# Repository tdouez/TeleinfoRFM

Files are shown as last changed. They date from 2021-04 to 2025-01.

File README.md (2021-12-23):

//--------------------------------------------------------------------
//   __|              _/           _ )  |
//   _| |  |   ` \    -_)   -_)    _ \  |   -_)  |  |   -_)
//  _| \_,_| _|_|_| \___| \___|   ___/ _| \___| \_,_| \___|
//--------------------------------------------------------------------
# TeleinfoRFM

Interface Téléinfo pour compteur Linky avec MySensors - version compatible modes historique et standard 

Projet utilisant un Arduino Pro mini et un module RFM95w

- Description disponible sur http://fumeebleue.fr

------------------------------------------------------------------------------------
Code mise à disposition selon les termes de la Licence Creative Commons Attribution
Pas d’Utilisation Commerciale.
Partage dans les Mêmes Conditions 4.0 International.
------------------------------------------------------------------------------------

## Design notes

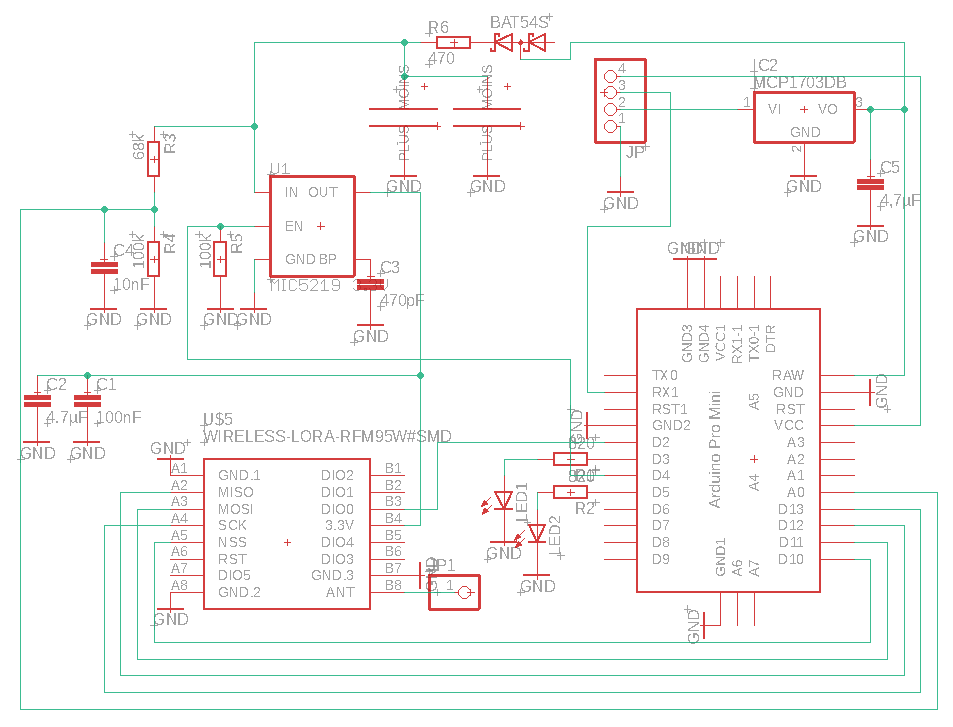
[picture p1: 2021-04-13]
Circuit TeleinfoRFM.png

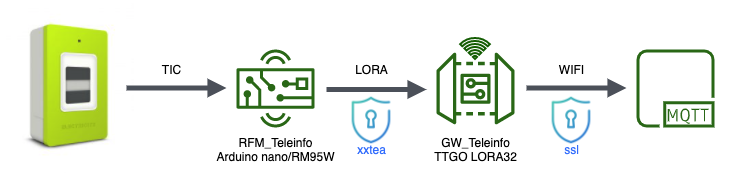
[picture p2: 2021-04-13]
TeleinfoRFM0.png

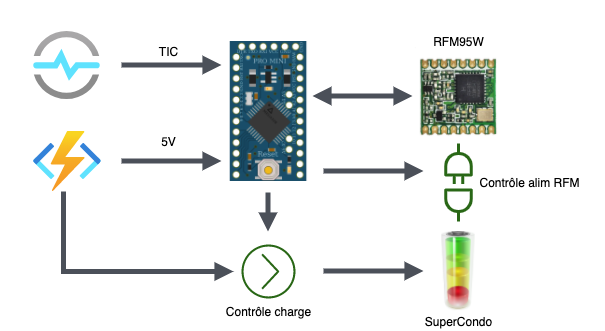
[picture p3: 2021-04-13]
TeleinfoRFM1.png

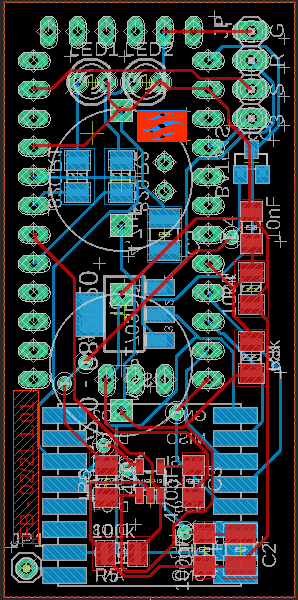
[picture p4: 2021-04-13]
PCB TeleinfoRFM.png

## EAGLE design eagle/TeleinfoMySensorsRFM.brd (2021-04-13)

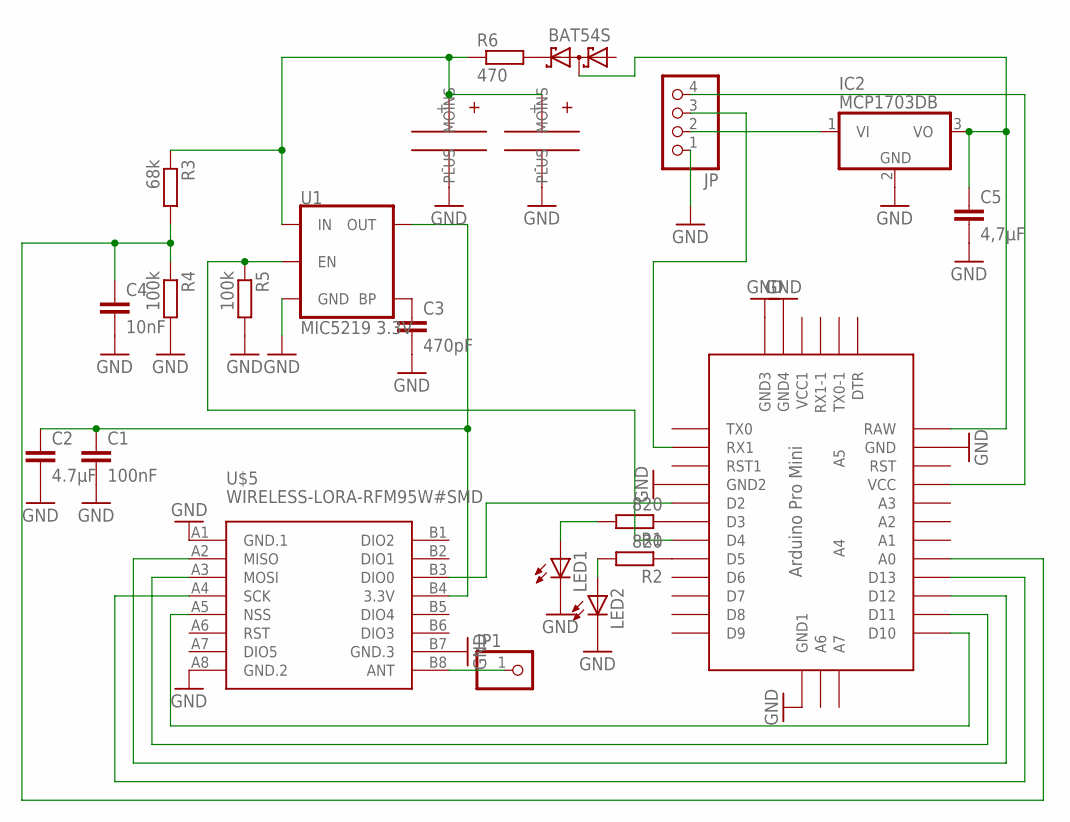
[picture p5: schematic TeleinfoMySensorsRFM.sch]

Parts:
C1: 100nF; C1206
C2: 4.7µF; C1210
C3: 470pF; C1206
C4: 10nF; C1206
C5: 4,7µF; C1210
D3: BAT54S; SOT23
IC2: MCP1703DB; SOT223
JP: PINHD-1X4; 1X04
JP1: PINHD-1X1; 1X01
LED1, LED2: LED3MM
R1, R2: 820; M1206
R3: 68k; M1206
R4, R5: 100k; M1206
R6: 470; M1206
U1: MIC5219 3.3V; SOT23-5
U$1: ABK-PRO-MINI
U$2, U$6: SUPERCAPA10
U$5: WIRELESS-LORA-RFM95W#SMD

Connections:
GND: C1.2, C2.2, C3.2, C4.2, C5.2, IC2.2 (GND), JP.1, LED1.K (C), LED2.K (C), R4.2, R5.2, U1.2 (GND), U$1.GND, U$1.GND1 (GND2), U$1.GND2 (GND3), U$1.GND3 (GND4), U$1.GND4 (GND1), U$2.- (MOINS), U$5.A1 (GND.1), U$5.A8 (GND.2), U$5.B7 (GND.3), U$6.- (MOINS)
unnamed: JP1.1, U$5.B8 (ANT)
unnamed: LED2.A, R2.2
unnamed: U$1.D12, U$5.A2 (MISO)
unnamed: R1.1, U$1.D3
unnamed: IC2.1 (VI), JP.2
unnamed: U$1.D11, U$5.A3 (MOSI)
unnamed: U$1.D13, U$5.A4 (SCK)
unnamed: U$1.D10, U$5.A5 (NSS)
unnamed: R2.1, U$1.D5
unnamed: U$1.D2, U$5.B3 (DIO0)
unnamed: LED1.A, R1.2
unnamed: JP.3, U$1.RX1
unnamed: C3.1, U1.4 (BP)
unnamed: C5.1, D3.3 (C1A2), IC2.3 (VO), U$1.RAW
unnamed: R5.1, U1.3 (EN), U$1.D4
unnamed: C4.1, R3.2, R4.1, U$1.A0
unnamed: C1.1, C2.1, U1.5 (OUT), U$5.B4 (3.3V)
unnamed: JP.4, U$1.VCC
unnamed: D3.2 (C2), R6.2
unnamed: R3.1, R6.1, U1.1 (IN), U$2.+ (PLUS), U$6.+ (PLUS)

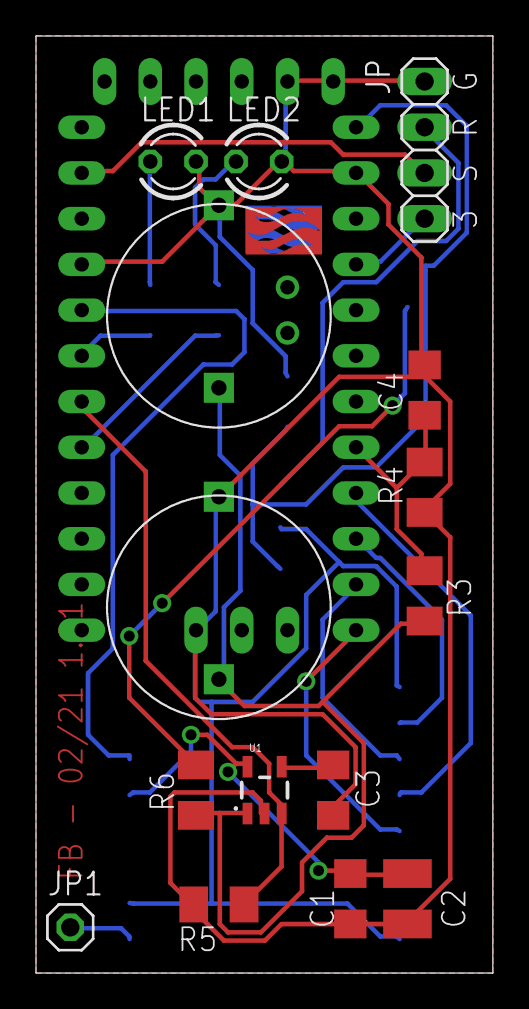
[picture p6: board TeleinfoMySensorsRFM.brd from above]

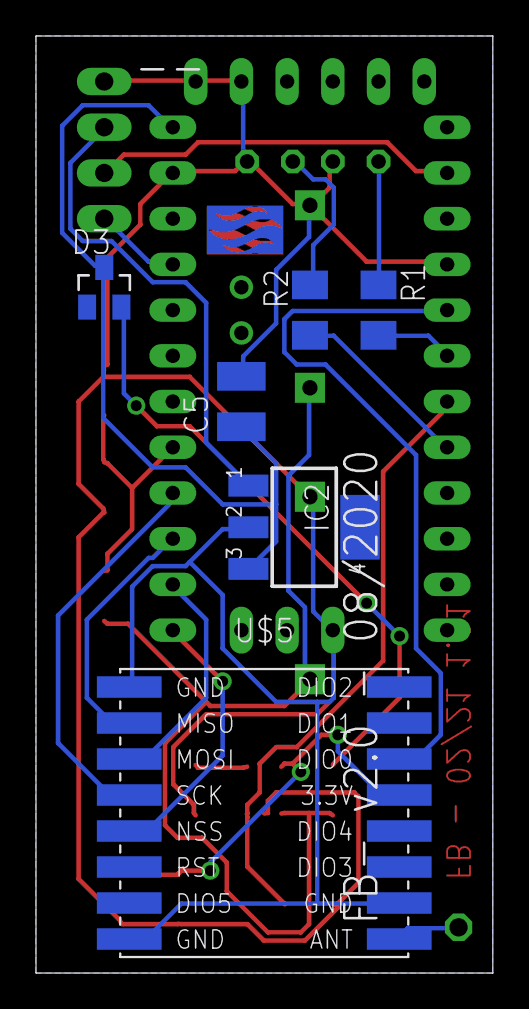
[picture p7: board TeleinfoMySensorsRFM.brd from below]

Board: 2 copper layers, 25.4 x 52.1 mm, 24 parts (7 on the bottom side), 21 nets.

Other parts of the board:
U$3, U$4: FB

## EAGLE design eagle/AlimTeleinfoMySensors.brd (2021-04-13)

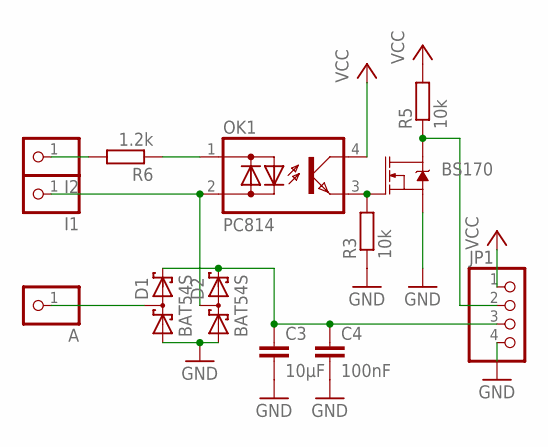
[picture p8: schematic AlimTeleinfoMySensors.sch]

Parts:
A: PINHD-1X1; 1X01
BS170: MOSFET-NCH-BSS138; SOT23-3
C3: 10µF; C1210
C4: 100nF; C1206
D1, D2: BAT54S; SOT23
I1, I2: PINHD-1X1; 1X01
JP1: PINHD-1X4; 1X04
OK1: PC814; DIL04
R3, R5: 10k; M1206
R6: 1.2k; M1206

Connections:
GND: BS170.2 (S), C3.2, C4.2, D1.1 (A1), D2.1 (A1), JP1.4, R3.1
unnamed: I2.1, R6.2
unnamed: D2.3 (C1A2), I1.1, OK1.2 (AC2)
unnamed: BS170.3 (D), JP1.2, R5.1
unnamed: C3.1, C4.1, D1.2 (C2), D2.2 (C2), JP1.3
unnamed: OK1.1 (AC1), R6.1
unnamed: BS170.1 (G), OK1.3 (E), R3.2
unnamed: A.1, D1.3 (C1A2)
VCC: JP1.1, OK1.4 (C), R5.2

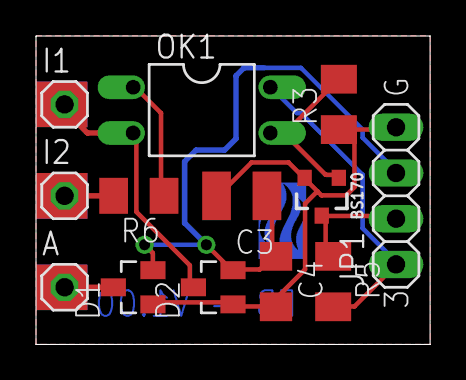
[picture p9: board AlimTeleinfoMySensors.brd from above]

Board: 2 copper layers, 21.9 x 17.1 mm, 14 parts (0 on the bottom side), 9 nets.

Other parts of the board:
U$1: FB

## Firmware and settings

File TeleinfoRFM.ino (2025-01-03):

//--------------------------------------------------------------------
//                 +/
//                 `hh-
//        ::        /mm:
//         hy`      -mmd
//         omo      +mmm.  -+`
//         hmy     .dmmm`   od-
//        smmo    .hmmmy    /mh
//      `smmd`   .dmmmd.    ymm
//     `ymmd-   -dmmmm/    omms
//     ymmd.   :mmmmm/    ommd.
//    +mmd.   -mmmmm/    ymmd-
//    hmm:   `dmmmm/    smmd-
//    dmh    +mmmm+    :mmd-
//    omh    hmmms     smm+
//     sm.   dmmm.     smm`
//      /+   ymmd      :mm
//           -mmm       +m:
//            +mm:       -o
//             :dy
//              `+:
//--------------------------------------------------------------------
//   __|              _/           _ )  |
//   _| |  |   ` \    -_)   -_)    _ \  |   -_)  |  |   -_)
//  _| \_,_| _|_|_| \___| \___|   ___/ _| \___| \_,_| \___|
//--------------------------------------------------------------------
// Code mise à disposition selon les termes de la Licence Creative Commons Attribution
// Pas d’Utilisation Commerciale.
// Partage dans les Mêmes Conditions 4.0 International.
//--------------------------------------------------------------------
// Trame : $origine;libelle;donnees   (libellé & donnnées)
//--------------------------------------------------------------------
// 2021/01/15 - FB V1.0.0
// 2021/06/11 - FB V1.0.1
// 2021/07/01 - FB V1.0.2 - Add ETIQU_URMS1..3
// 2021/11/21 - FB V1.0.3 - Bug fix  modes triphasé et producteur
// 2021/12/08 - FB V2.0.0 - Utilisation de la librairie libTeleinfo (https://github.com/hallard/LibTeleinfo) et chg protocole vers GW
// 2021/12/27 - FB V2.0.1 - Fix bug aléatoire, blocage envoi data
// 2022/01/07 - FB V2.0.2 - Optimisation utilisation mémoire et emissions datas. Ajout détection vitesse TIC.
// 2022/01/11 - FB V2.0.3 - Suppression warning et modif gestion timeout vitesse TIC
// 2022/01/23 - FB V2.0.4 - Correction sur détection TIC historique
// 2022/06/25 - FB V2.0.5 - Optimisation mémoire
// 2022/09/25 - FB V2.0.6 - Correction sur détection TIC standard
// 2023/03/23 - FB V2.0.7 - Ajout indication réception TIC et optimisation mémoire
// 2023/03/30 - FB V2.0.8 - Correction blocage aléatoire module, frequence maj 15 à 20s, clignotement durant charge condo
// 2023/05/04 - FB V2.0.9 - Amélioration détection mode TIC historique/standard
// 2023/06/03 - FB V2.0.10 - Correction detection TIC historique
// 2025/01/03 - FB V2.0.11 - Ajout compatibilité avec le Arduino Pro Micro
//--------------------------------------------------------------------

#include <Arduino.h>
#include <SPI.h>
#include <LoRa.h>
#include <LibTeleinfo.h>

//#define DEBUG_TIC

#ifdef __arm__
// should use uinstd.h to define sbrk but Due causes a conflict
extern "C" char* sbrk(int incr);
#else  // __ARM__
extern char *__brkval;
#endif  // __arm__

#define VERSION   "v2.0.11"

#define ENTETE  "$"

#define POWER_PIN         4
#define TELEINFO_LED_PIN  3   // Teleinfo LED
#define CHARGE_LED_PIN    5   // Charge LED

//-------------------------------------------------------------------------------------
// Seuil : 4,5v à l'entrée du régulateur 3,3v > 4,5v*100k/(100k+68k)=2,68v sur A0
//                                                 3,3v->1023 => 2,68->830
//-------------------------------------------------------------------------------------
#define SEUIL_CHARGE_FULL   815
#define SEUIL_CHARGE_98     805

#define RFM_TX_POWER   10   // 5..23 dB

boolean full_tic = true;
boolean flag_tic = true;
boolean flag_send_tic = true;
boolean flag_adresse_tic;
boolean flag_boot;

const char char_ADCO[] PROGMEM = "ADCO";
const char char_ADSC[] PROGMEM = "ADSC";
const unsigned long SEND_FREQUENCY_FULL = 180000; // 3mn, Minimum time between send (in milliseconds). 
const unsigned long SEND_FREQUENCY_TIC  =  20000; // 15s,  Minimum time between send (in milliseconds). 
unsigned long lastTime_full = 0;
unsigned long lastTime_tic = 0;
char adresse_compteur[13];
_Mode_e mode_tic;

TInfo tinfo;

/*
// ---------------------------------------------------------------- 
// freeMemory
// ---------------------------------------------------------------- 
int freeMemory() {
  char top;
#ifdef __arm__
  return &top - reinterpret_cast<char*>(sbrk(0));
#elif defined(CORE_TEENSY) || (ARDUINO > 103 && ARDUINO != 151)
  return &top - __brkval;
#else  // __arm__
  return __brkval ? &top - __brkval : &top - __malloc_heap_start;
#endif  // __arm__
}

// ---------------------------------------------------------------- 
// freeMemory
// ---------------------------------------------------------------- 
void affiche_freeMemory() {
	Serial.print(F("SRAM:"));
	Serial.println(freeMemory());
}
*/

// ---------------------------------------------------------------- 
// change_etat_led
// ---------------------------------------------------------------- 
void change_etat_led(uint8_t led)
{
  static uint8_t led_state;

  led_state = !led_state;
  digitalWrite(led, led_state);

}

// ---------------------------------------------------------------- 
// clignote_led
// ---------------------------------------------------------------- 
void clignote_led(uint8_t led, uint8_t nbr, int16_t delais)
{
uint8_t led_state=0;

  for (uint8_t i=0; i<nbr*2; i++) {
    led_state = !led_state;
    digitalWrite(led, led_state);
    delay(delais);
  }
  digitalWrite(led, LOW);
}

// ---------------------------------------------------------------- 
// init_speed_TIC
// ---------------------------------------------------------------- 
_Mode_e init_speed_TIC()
{
boolean flag_timeout = false;
boolean flag_found_speed = false;
uint32_t currentTime = millis();
uint8_t step = 0;
int nbc_etiq=0;
int nbc_val=0;
_Mode_e mode;

  digitalWrite(TELEINFO_LED_PIN, HIGH);
  digitalWrite(CHARGE_LED_PIN, HIGH);
  
  // Test en mode historique
  // Recherche des éléments de début, milieu et fin de trame 
  #if defined(__AVR_ATmega32U4__)
  Serial.begin(9600);
  Serial1.begin(1200); // mode historique
  #else
  Serial.begin(1200); // mode historique
  #endif
  Serial.println(F("Recherche mod TIC"));

  while (!flag_timeout && !flag_found_speed) {
    #if defined(__AVR_ATmega32U4__)
    if (Serial1.available()>0) {
      char in = (char)Serial1.read() & 127;  // seulement sur 7 bits
    #else
    if (Serial.available()>0) {
      char in = (char)Serial.read() & 127;  // seulement sur 7 bits
    #endif

      #ifdef DEBUG_TIC
      Serial.print(in, HEX);
      Serial.println(".");
      #endif
      // début trame
      if (in == 0x0A) {
        step = 1;
        nbc_etiq = -1;
        nbc_val = 0;
        #ifdef DEBUG_TIC
          Serial.println(F("Deb 0x0A"));
        #endif
      }

      // début trame
      if (step == 1) {
        if (in == 0x20) {
          #ifdef DEBUG_TIC
            Serial.print(F("Etq 0x20:"));
            Serial.println(nbc_etiq);
          #endif
          if (nbc_etiq > 3 && nbc_etiq < 10) step = 2;
            else step = 0;
        }
        else nbc_etiq++; // recupère nombre caractères de l'étiquette
      }
      else {
        // deuxième milieu de trame, valeur
        if (step == 2) {
          if (in == 0x20) {
            #ifdef DEBUG_TIC
              Serial.print(F("Val 0x20:"));
              Serial.println(nbc_val);
            #endif
            if (nbc_val > 0 && nbc_val < 13) step = 3;
              else step = 0;
          }
          else nbc_val++; // recupère nombre caractères de la valeur
        }
      }

      // fin trame
      if (step == 3 && in == 0x0D) {
        #ifdef DEBUG_TIC
          Serial.println(F("Fin 0x0D"));
        #endif
        flag_found_speed = true;
        step = 0;
      }
    }
    if (currentTime + 10000 <  millis()) flag_timeout = true; // 10s de timeout
  }

  if (flag_timeout) { // trame avec vistesse histo non trouvée donc passage en mode standard
     mode = TINFO_MODE_STANDARD;
     #if defined(__AVR_ATmega32U4__)
     Serial1.end();
     Serial1.begin(9600); // mode standard
     #else
     Serial.end();
     Serial.begin(9600); // mode standard
     #endif
     Serial.println(F(">> TIC mode standard <<"));
     clignote_led(CHARGE_LED_PIN, 3, 500);
  }
  else {
    mode = TINFO_MODE_HISTORIQUE;
    Serial.println(F(">> TIC mode historique <<"));
    clignote_led(CHARGE_LED_PIN, 5, 200);
  }
  
  digitalWrite(TELEINFO_LED_PIN, LOW);

  return mode;
}

// ---------------------------------------------------------------- 
// send_boot
//    Envoi info au démarrge avec version
// ---------------------------------------------------------------- 
void send_boot() 
{

  verif_charge_condo(SEUIL_CHARGE_FULL);
  start_rf95();
  LoRa.beginPacket();    // start packet
  LoRa.print(ENTETE);  
  LoRa.print(F("Linky_")); 
  LoRa.print(adresse_compteur); 
  LoRa.print(F(";VERSION;")); 
  LoRa.print(VERSION); 
  LoRa.print(F(";"));
  LoRa.endPacket();      // finish packet and send it
  delay(20);
  stop_rf95();
}

// ---------------------------------------------------------------- 
// search_adress_teleinfo
//    Envoi trame de teleinfo
// ---------------------------------------------------------------- 
void search_adress_teleinfo(ValueList *vl_tic)
{

  if (vl_tic) {
    // parcours liste chainée vl_tic
    while (vl_tic->next) {
      vl_tic = vl_tic->next;
      if (vl_tic->name && strlen(vl_tic->name) && vl_tic->value && strlen(vl_tic->value)) {
        if (strstr_P(vl_tic->name, char_ADCO) == 0 || strstr_P(vl_tic->name, char_ADSC) == 0) {
          strncpy(adresse_compteur, vl_tic->value, 12);
          Serial.print(F("Adr cpt: "));
          Serial.println(adresse_compteur);
          flag_adresse_tic = true;
          break;
         }
      }
    }
  }
  digitalWrite(TELEINFO_LED_PIN, LOW);
}

// ---------------------------------------------------------------- 
// charge_condo
//    charge le super condo avec gestion led 
// ---------------------------------------------------------------- 
void charge_condo(int ref_seuil)
{
boolean flag_cap = false;

  Serial.print(F(">> Charge Condo.."));
  digitalWrite(CHARGE_LED_PIN, HIGH);
  digitalWrite(TELEINFO_LED_PIN, LOW);

  while (flag_cap == false) {
	if (analogRead(A0) >= ref_seuil) flag_cap = true;
	else {
		change_etat_led(CHARGE_LED_PIN);
		delay(300);
	}
  }
  digitalWrite(CHARGE_LED_PIN, LOW);
  Serial.println(F(". done"));
}

// ---------------------------------------------------------------- 
// test_charge_condo
//    test niveau tension sur le super condo. 
//    retourne vrai si niveau suffisant
// ---------------------------------------------------------------- 
boolean test_charge_condo(int ref_seuil)
{
  if (analogRead(A0) < ref_seuil) return false;

  return true;
}

// ---------------------------------------------------------------- 
// test_charge_condo
//    verif niveau tension sur le super condo
//    lance la charge si niveau insuffisant
// ---------------------------------------------------------------- 
void verif_charge_condo(int ref_seuil)
{
  if (test_charge_condo(ref_seuil) == false) charge_condo(ref_seuil);  
}

// ---------------------------------------------------------------- 
// send_teleinfo
//    Envoi trame de teleinfo
// ---------------------------------------------------------------- 
void send_teleinfo(ValueList *vl_tic, boolean all_tic)
{
  
  if (vl_tic && flag_tic) {

    // parcours liste chainée vl_tic
    while (vl_tic->next) {
      vl_tic = vl_tic->next;
      // uniquement sur les nouvelles valeurs ou celles modifiées ou toutes
      if ( all_tic || ( vl_tic->flags & (TINFO_FLAGS_UPDATED | TINFO_FLAGS_ADDED) )) {
        if (vl_tic->name && strlen(vl_tic->name) > 2 && vl_tic->value && strlen(vl_tic->value) > 1) {
          Serial.print(F("Send "));
          Serial.print(vl_tic->name);
          Serial.print(F(":"));
          Serial.println(vl_tic->value);

    		  verif_charge_condo(SEUIL_CHARGE_98);
			    start_rf95();
    		  LoRa.beginPacket();    // start packet
    		  LoRa.print(ENTETE);  
    		  LoRa.print(F("Linky_")); 
    		  LoRa.print(adresse_compteur); 
    		  LoRa.print(F(";"));
    		  LoRa.print(vl_tic->name); 
    		  LoRa.print(F(";"));
    		  LoRa.print(vl_tic->value); 
    		  LoRa.print(F(";"));
    		  LoRa.endPacket();      // finish packet and send it
			    delay(20);
			    stop_rf95();
        }
      }
    }
    flag_tic = false;
  }
}

/* ======================================================================
Function: NewFrame 
Purpose : callback when we received a complete teleinfo frame
Input   : linked list pointer on the concerned data
Output  : - 
Comments: -
====================================================================== */
void NewFrame(ValueList *vl_tic)
{
  //affiche_freeMemory();
  
  if (!flag_adresse_tic) search_adress_teleinfo(vl_tic);
    else send_teleinfo(vl_tic, full_tic);
    
  if (full_tic) full_tic = false;
  
}

/* ======================================================================
Function: NewFrame 
Purpose : callback when we received a complete teleinfo frame
Input   : linked list pointer on the concerned data
Output  : - 
Comments: it's called only if one data in the frame is different than
          the previous frame
====================================================================== */
void UpdatedFrame(ValueList *vl_tic)
{
  //affiche_freeMemory();
  
  if (!flag_adresse_tic) search_adress_teleinfo(vl_tic);
    else send_teleinfo(vl_tic, full_tic);
    
  if (full_tic) full_tic = false;
}

/* ======================================================================
Function: DataCallback 
Purpose : callback when we detected new or modified data received
Input   : linked list pointer on the concerned data
          current flags value
Output  : - 
Comments: -
====================================================================== */
void DataCallback(ValueList * me, uint8_t  flags)
{

  change_etat_led(TELEINFO_LED_PIN);
    
}

// ---------------------------------------------------------------- 
// start_rf95
// ---------------------------------------------------------------- 
boolean start_rf95()
{
boolean rc = false;

  // activation alim et init RFM
  digitalWrite(POWER_PIN, HIGH);
  if (LoRa.begin(868E6)) {
	LoRa.enableCrc();
	LoRa.setTxPower(RFM_TX_POWER);
	rc = true;
  }
  else {
	rc = false;
	Serial.println(F("Starting LoRa failed!"));
  }
  
  return rc;
}

// ---------------------------------------------------------------- 
// stop_rf95
// ---------------------------------------------------------------- 
void stop_rf95()
{
	digitalWrite(POWER_PIN, LOW);
}

// ---------------------------------------------------------------- 
// setup
// ---------------------------------------------------------------- 
void setup()
{
  pinMode(TELEINFO_LED_PIN, OUTPUT);
  pinMode(CHARGE_LED_PIN, OUTPUT);
  pinMode(POWER_PIN, OUTPUT);
  
  digitalWrite(POWER_PIN, LOW);
  digitalWrite(TELEINFO_LED_PIN, LOW);
  digitalWrite(CHARGE_LED_PIN, LOW);

  delay(2000);

  // init interface série suivant mode TIC
  mode_tic = init_speed_TIC();
  //Serial.begin(MODE_TIC == TINFO_MODE_HISTORIQUE ? 1200 : 9600);

  Serial.println(F("   __|              _/           _ )  |"));
  Serial.println(F("   _| |  |   ` \\    -_)   -_)    _ \\  |   -_)  |  |   -_)"));
  Serial.println(F("  _| \\_,_| _|_|_| \\___| \\___|   ___/ _| \\___| \\_,_| \\___|"));
  Serial.print(F("                                             "));
  Serial.println(VERSION);

  // première charge super condo
  verif_charge_condo(SEUIL_CHARGE_FULL);

  flag_boot = true;
  flag_adresse_tic = false;
  
  // init interface TIC
  tinfo.init(mode_tic);
  tinfo.attachData(DataCallback);
  tinfo.attachNewFrame(NewFrame);
  tinfo.attachUpdatedFrame(UpdatedFrame);

}


// ---------------------------------------------------------------- 
// loop
// ---------------------------------------------------------------- 
void loop()
{
uint32_t currentTime = millis();

  #if defined(__AVR_ATmega32U4__)
  if (Serial1.available()) tinfo.process(Serial1.read());
  #else
  if (Serial.available()) tinfo.process(Serial.read());
  #endif
  
  if (flag_adresse_tic) {
	  
    if (flag_boot) {
      // envoi version au démarrage
      send_boot();
      flag_boot = false;
    }
    
    // envoyer l'ensemble des données tous les SEND_FREQUENCY_FULL ms
    if (currentTime - lastTime_full > SEND_FREQUENCY_FULL) {
      //Serial.println(F("SEND_FREQUENCY_FULL"));
      full_tic = true;
      flag_tic = true;
      lastTime_full = currentTime;
    }
  
    // envoyer les données tous les SEND_FREQUENCY_TIC ms
    if (currentTime - lastTime_tic > SEND_FREQUENCY_TIC) {
      //Serial.println(F("SEND_FREQUENCY_TIC"));
      flag_tic = true;
      lastTime_tic = currentTime;
    }
  }

}

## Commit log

2021-11-21 V1.0.3
    Correction bug sur mode triphasé et producteur
    [TeleinfoRFM.ino]
2021-12-23 V2.00
    Utilisation de la librairie libTeleinfo (https://github.com/hallard/LibTeleinfo) et chg protocole vers GW
    Compatible uniquement avec la version logicielle de la gateway > V2.x
2021-12-27 V2.0.1
    Fix bug aléatoire, blocage envoi data
    [TeleinfoRFM.ino]
2022-01-25 2.0.4
    Correction sur détection TIC historique
    [TeleinfoRFM.ino]
2022-09-27 V2.0.6
    Correction sur détection TIC standard
    [TeleinfoRFM.ino]
2023-03-30 v2.0.8
    Correction blocage aléatoire module, frequence maj 15 à 20s, clignotement durant charge condo
    [TeleinfoRFM.ino]
2023-06-03 V2.0.10
    Correction detection TIC historique
    [TeleinfoRFM.ino]
2025-01-03 V2.0.11
    Ajout compatibilité avec le Arduino Pro Micro

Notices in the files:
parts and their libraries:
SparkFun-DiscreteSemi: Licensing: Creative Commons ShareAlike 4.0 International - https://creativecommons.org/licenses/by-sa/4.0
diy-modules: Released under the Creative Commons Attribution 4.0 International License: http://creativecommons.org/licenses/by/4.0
